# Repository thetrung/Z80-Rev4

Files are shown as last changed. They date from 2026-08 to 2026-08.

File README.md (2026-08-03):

# Z80 Homebrew with PIC18/F4520 
Rev4 of Z80 + PIC18/F4520 setup.

### Note
I have never had a real working Z80 before so this board is designed to test that if I can get one.

### 3D Preview 
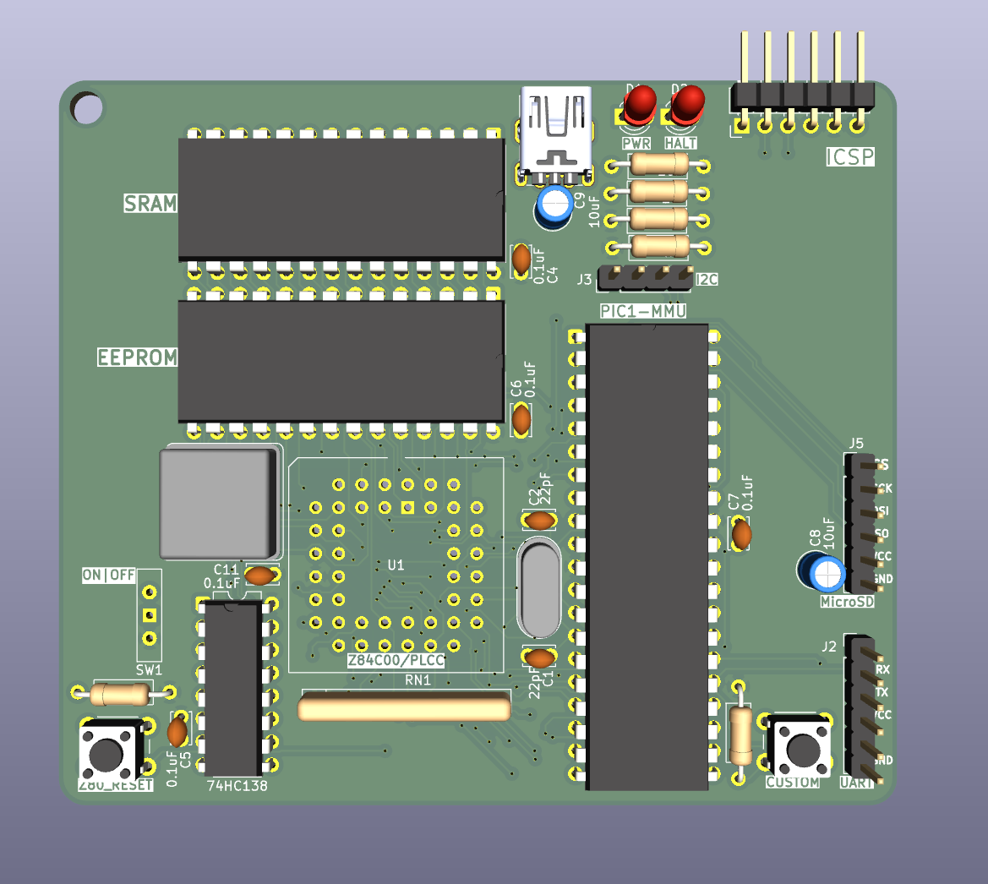
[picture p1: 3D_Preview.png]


### Placement (SilkScreen)
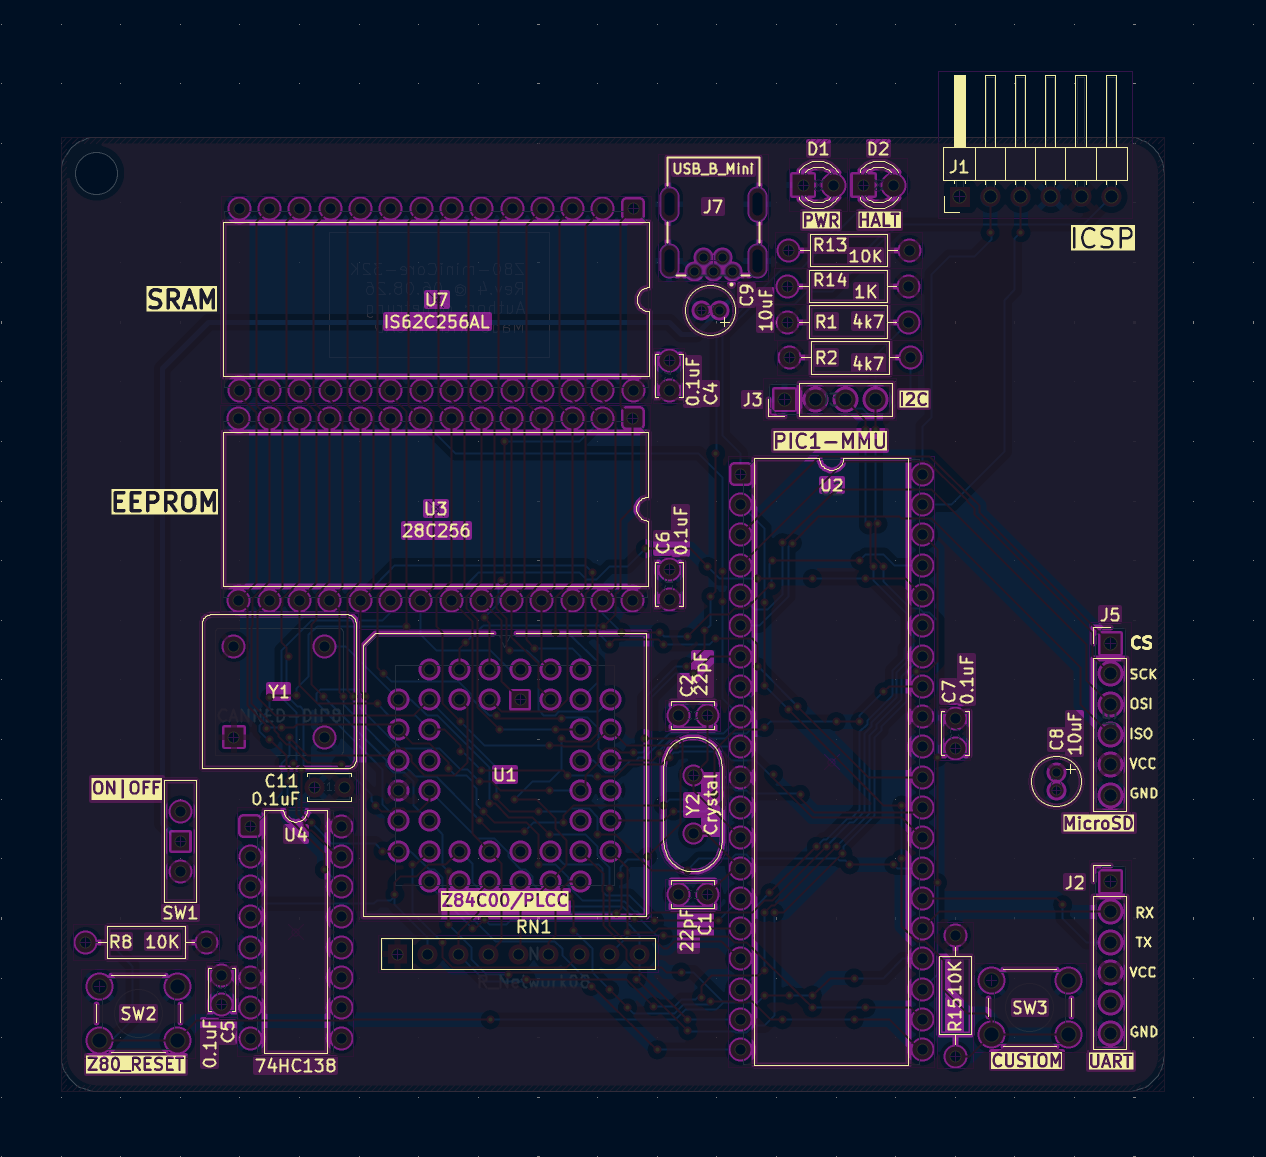
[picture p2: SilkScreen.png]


### Schematic 
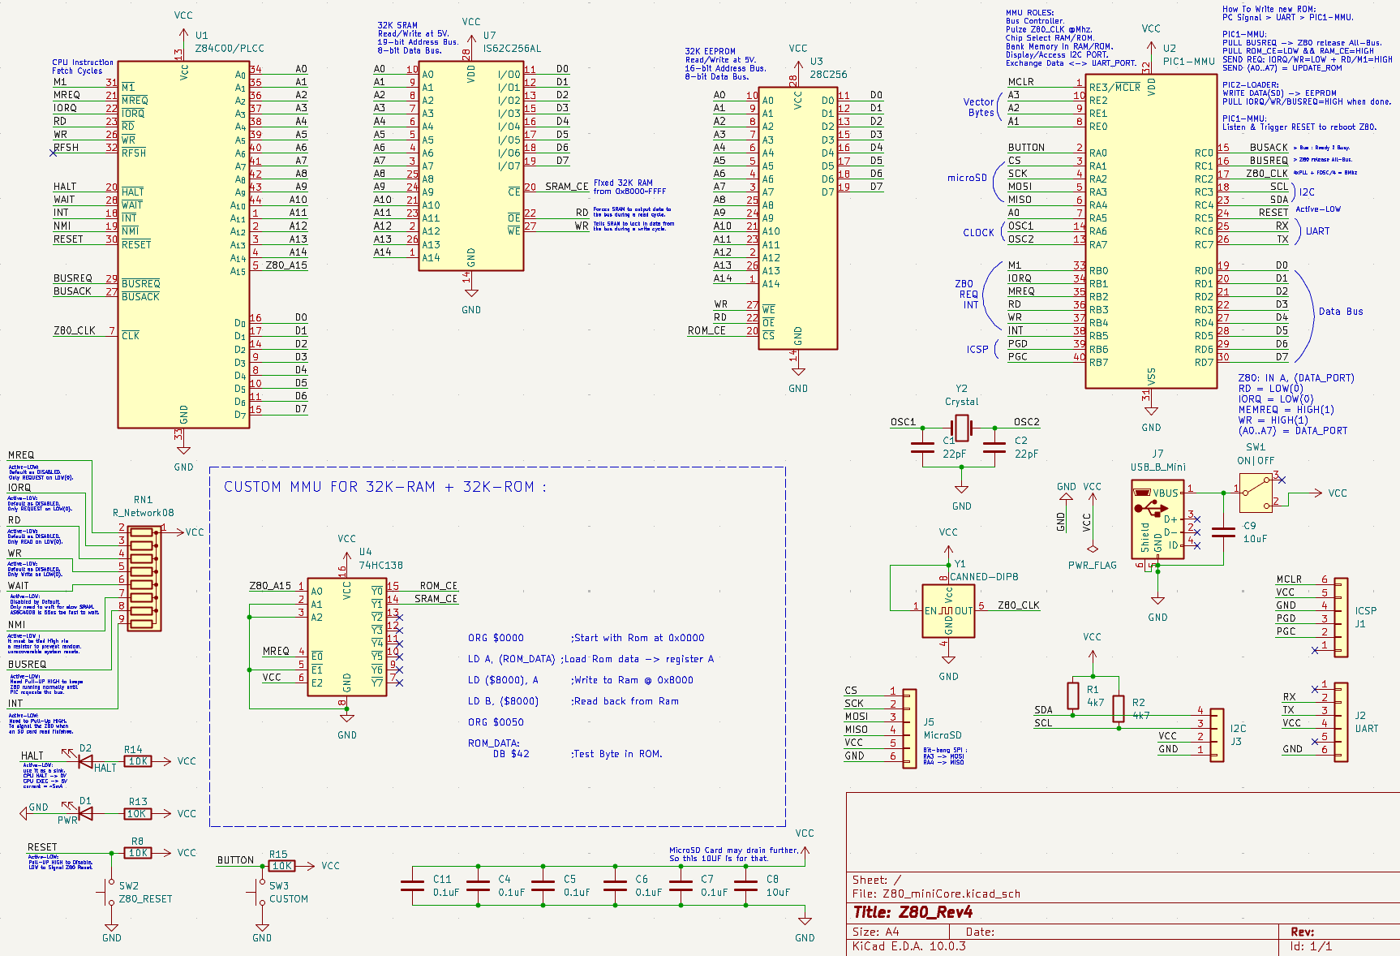
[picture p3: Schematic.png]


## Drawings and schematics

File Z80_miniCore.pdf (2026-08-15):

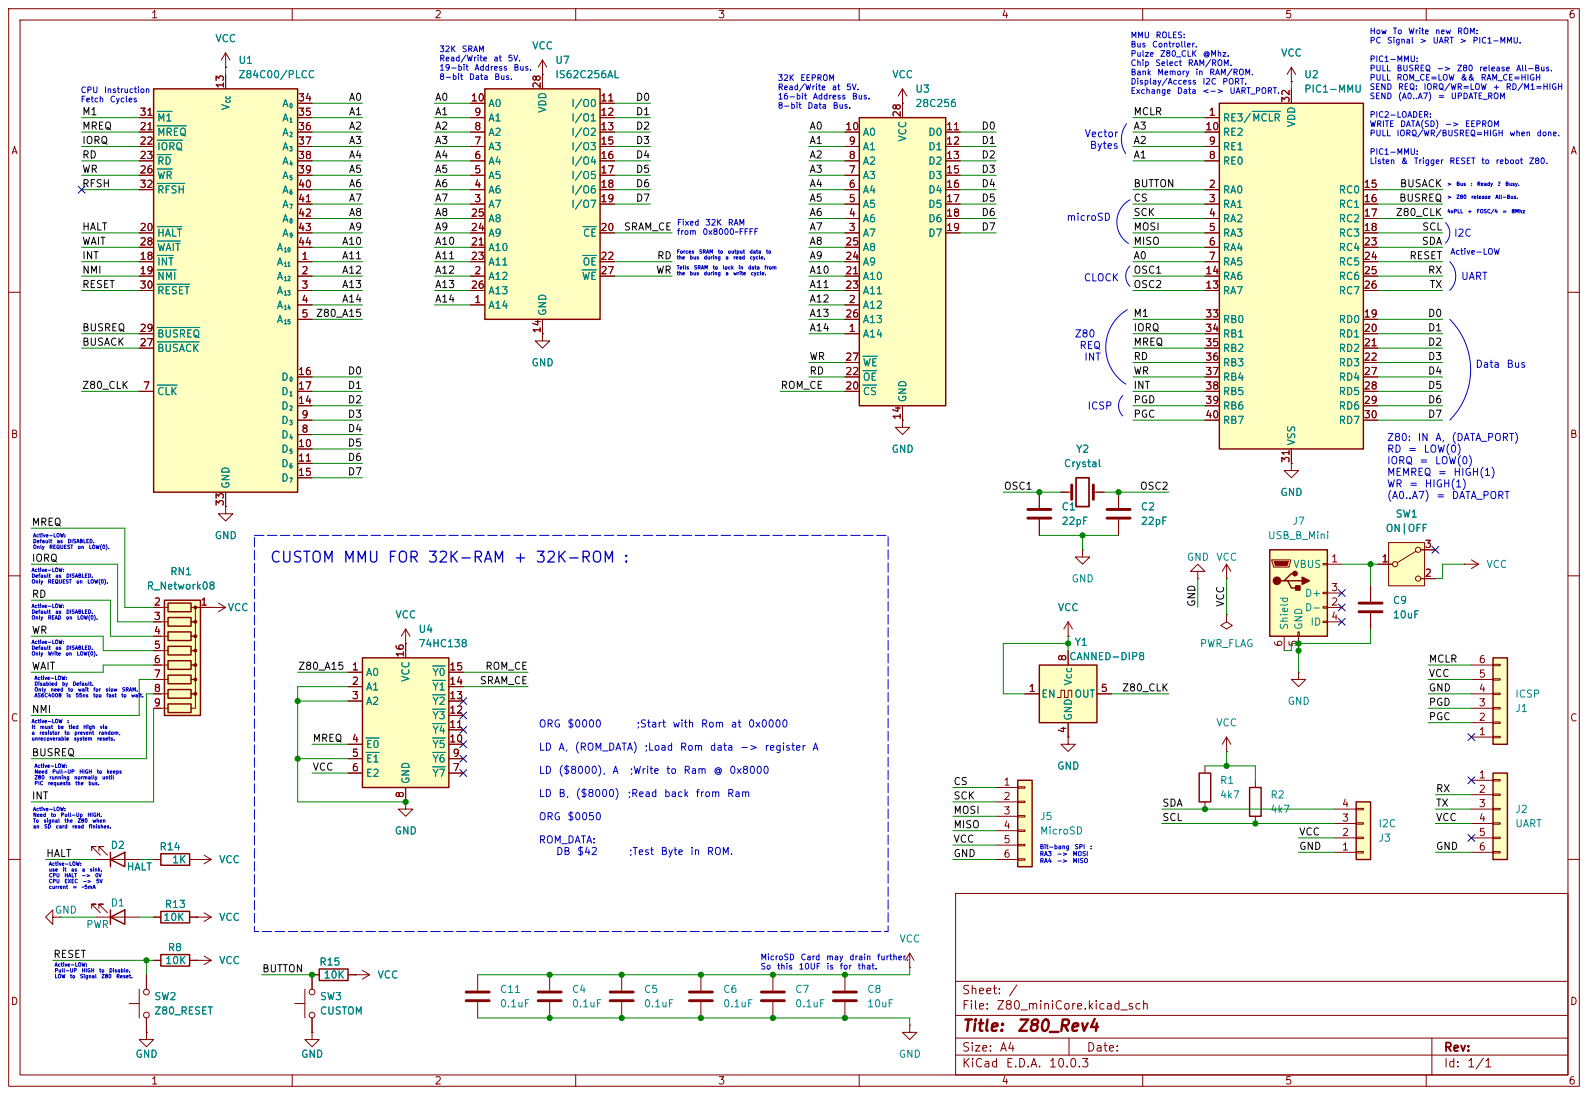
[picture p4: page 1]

VCC U1
INT 18 NMI 19 HALT 20 MREQ 21

MMU ROLES: Bus Controller. Pulze Z80_CLK @Mhz. Chip Select RAM/ROM. Bank Memory in RAM/ROM. Display/Access I2C PORT. Exchange Data <-> UART_PORT.

> Bus : Ready ? Busy. How To Write new ROM: PC Signal > UART > PIC1-MMU. PIC1-MMU: PULL BUSREQ -> Z80 release All-Bus. PULL ROM_CE=LOW && RAM_CE=HIGH
VCC U3

Z84C00/PLCC

32K EEPROM Read/Write at 5V. 16-bit Address Bus. 8-bit Data Bus.

SEND REQ: IORQ/WR=LOW + RD/M1=HIGH
SEND (A0..A7) = UPDATE_ROM

PIC2-LOADER: WRITE DATA(SD) -> EEPROM

PULL IORQ/WR/BUSREQ=HIGH when done. PIC1-MMU: Listen & Trigger RESET to reboot Z80. > Z80 release All-Bus.

Forces SRAM to output data to

Tells SRAM to lock in data from

IORQ = MEMREQ = HIGH(1) WR = HIGH(1)
10uF SW1 ON|OFF 1

(A0..A7) = DATA_PORT MicroSD Card may drain further, So this 10UF is for that.

Active-LOW: Default as DISABLED. Only Write on LOW(0). Active-LOW: Default as DISABLED. Only READ on LOW(0).

Active-LOW :
It must be tied High via a resistor to prevent random, unrecoverable system resets.

LD A, (ROM_DATA) ;Load Rom data -> register A

Active-LOW: Need Pull-UP HIGH to keeps Z80 running normally until PIC requests the bus.

LD ($8000), A ;Write to Ram @ 0x8000

Bit-bang SPI : RA3 -> MOSI RA4 -> MISO

Active-LOW: use it as a sink. CPU HALT -> 0V CPU EXEC -> 5V

Active-LOW: Pull-UP HIGH to Disable. LOW to Signal Z80 Reset.

Size: A4 | Rev:
KiCad E.D.A. 10.0.3 | Id: 1/1

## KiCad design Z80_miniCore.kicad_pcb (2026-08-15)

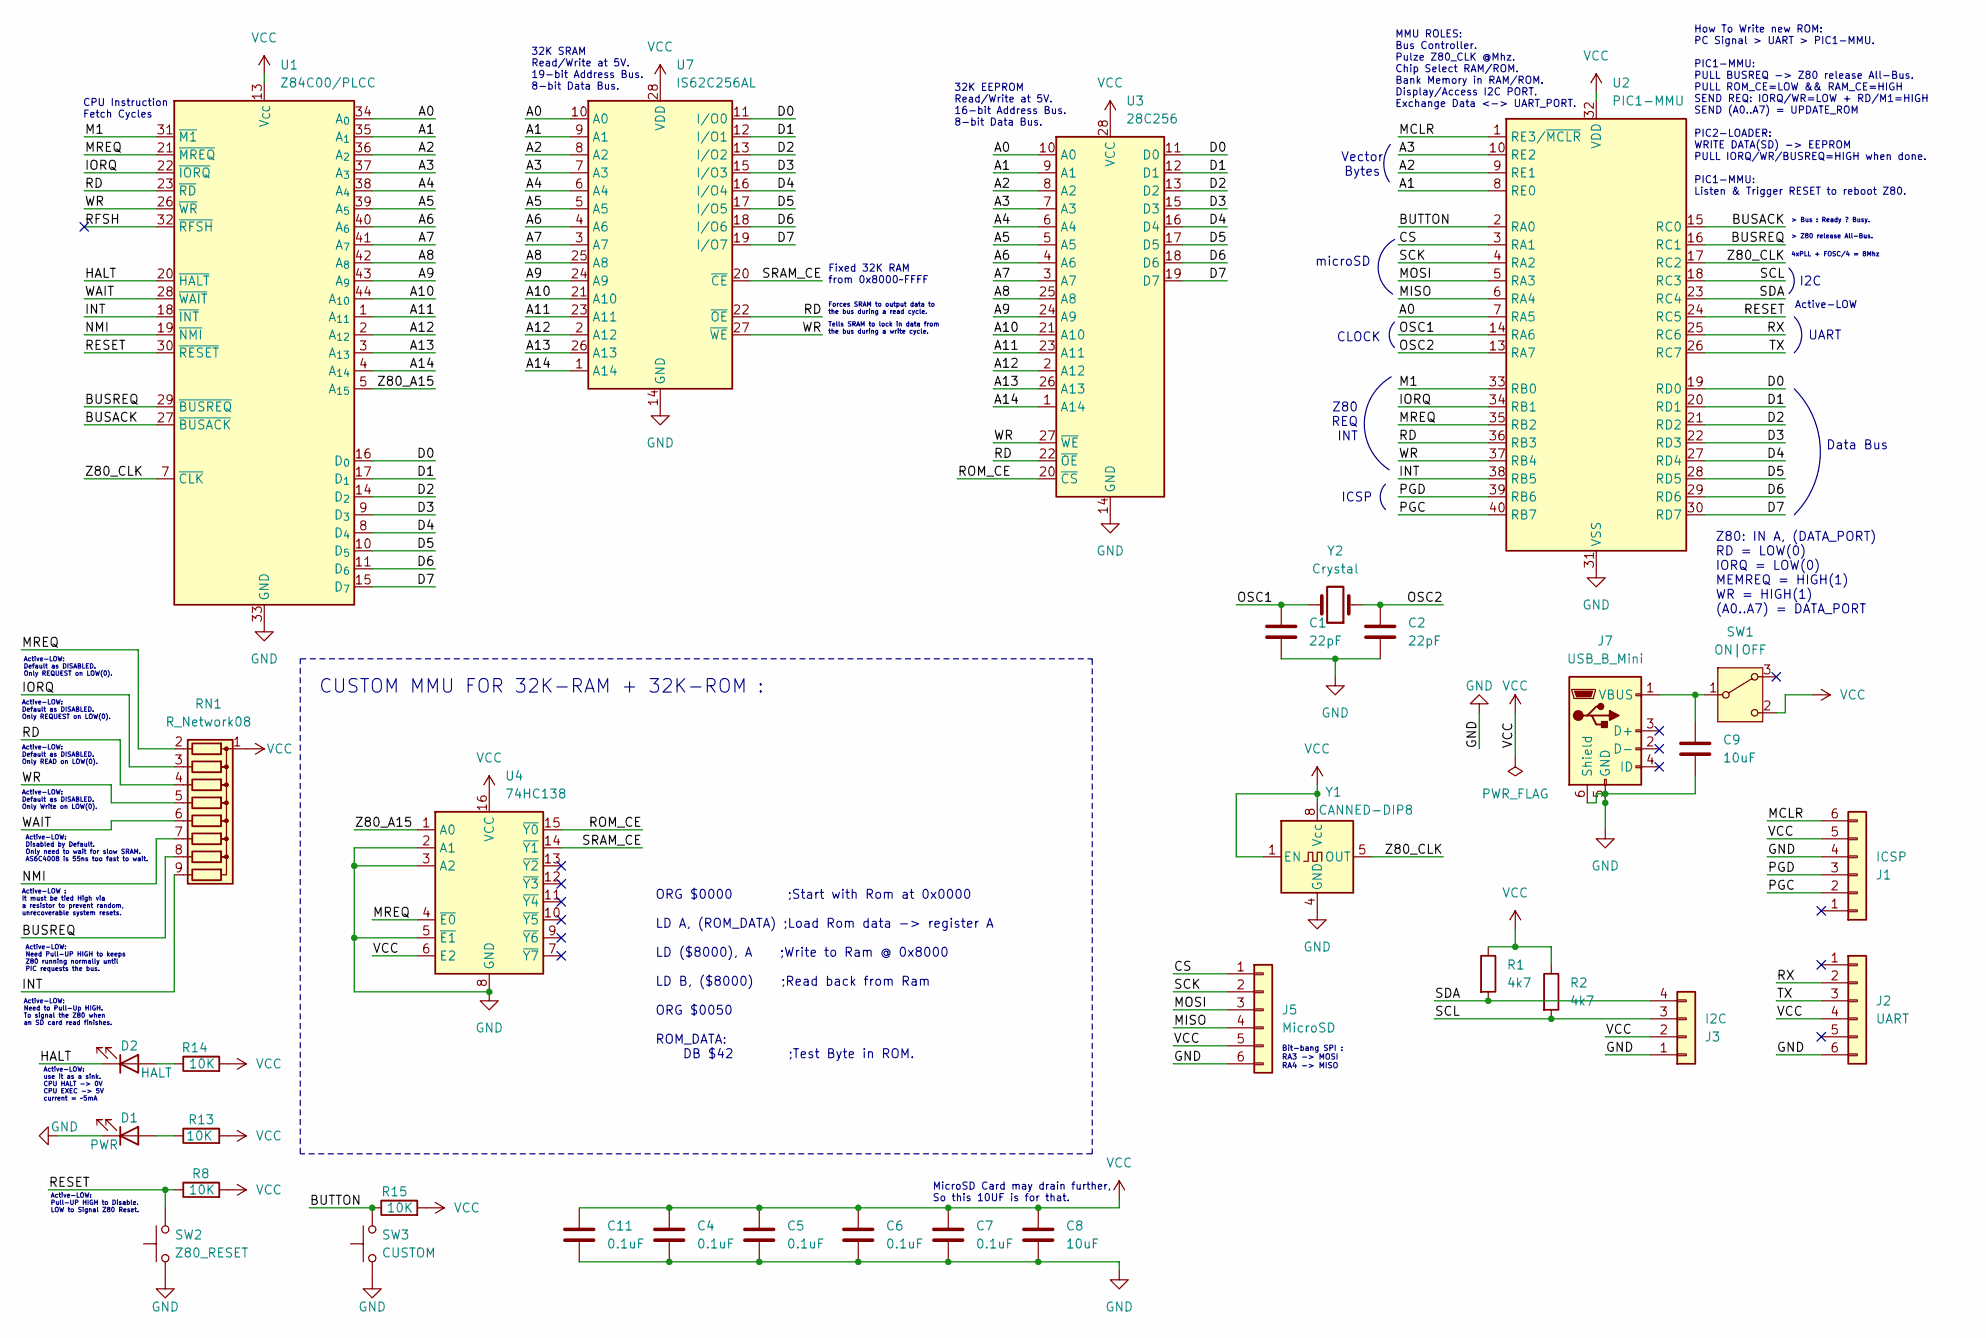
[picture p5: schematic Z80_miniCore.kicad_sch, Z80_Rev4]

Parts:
C1, C2: 22pF; C_Disc_D3.4mm_W2.1mm_P2.50mm
C4, C5, C6, C7, C11: 0.1uF; C_Disc_D3.4mm_W2.1mm_P2.50mm
C8, C9: 10uF; C_Radial_D4.0mm_H5.0mm_P1.50mm
D1: PWR; LED_D3.0mm
D2: HALT; LED_D3.0mm
J1: ICSP; PinHeader_1x06_P2.54mm_Horizontal
J2: UART; PinHeader_1x06_P2.54mm_Vertical
J3: I2C; PinHeader_1x04_P2.54mm_Vertical
J5: MicroSD; PinHeader_1x06_P2.54mm_Vertical
J7: USB_B_Mini; USB_MINI_B_90_Angled
R1, R2: 4k7; R_Axial_DIN0207_L6.3mm_D2.5mm_P10.16mm_Horizontal
R8, R13, R14, R15: 10K; R_Axial_DIN0207_L6.3mm_D2.5mm_P10.16mm_Horizontal
RN1: R_Network08; R_Array_SIP9
SW1: ON|OFF; SW_Slide-03_Wuerth-WS-SLTV_10x2.5x6.4_P2.54mm
SW2: Z80_RESET; SW_PUSH_6mm
SW3: CUSTOM; SW_PUSH_6mm
U1: Z84C00/PLCC; PLCC-44_THT-Socket
U2: PIC1-MMU; DIP-40_W15.24mm
U3: 28C256; DIP-28_W15.24mm
U4: 74HC138; DIP-16_W7.62mm
U7: IS62C256AL; DIP-28_W15.24mm
Y1: CANNED-DIP8; Oscillator_DIP-8
Y2: Crystal; Crystal_HC49-4H_Vertical

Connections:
/A0: U1.34 (A_{0}), U2.7 (RA5), U3.10 (A0), U7.10 (A0)
/A1: U1.35 (A_{1}), U2.8 (RE0), U3.9 (A1), U7.9 (A1)
/A2: U1.36 (A_{2}), U2.9 (RE1), U3.8 (A2), U7.8 (A2)
/A3: U1.37 (A_{3}), U2.10 (RE2), U3.7 (A3), U7.7 (A3)
/A4: U1.38 (A_{4}), U3.6 (A4), U7.6 (A4)
/A5: U1.39 (A_{5}), U3.5 (A5), U7.5 (A5)
/A6: U1.40 (A_{6}), U3.4 (A6), U7.4 (A6)
/A7: U1.41 (A_{7}), U3.3 (A7), U7.3 (A7)
/A8: U1.42 (A_{8}), U3.25 (A8), U7.25 (A8)
/A9: U1.43 (A_{9}), U3.24 (A9), U7.24 (A9)
/A10: U1.44 (A_{10}), U3.21 (A10), U7.21 (A10)
/A11: U1.1 (A_{11}), U3.23 (A11), U7.23 (A11)
/A12: U1.2 (A_{12}), U3.2 (A12), U7.2 (A12)
/A13: U1.3 (A_{13}), U3.26 (A13), U7.26 (A13)
/A14: U1.4 (A_{14}), U3.1 (A14), U7.1 (A14)
/BUSACK: U1.27 (~BUSACK), U2.15 (RC0)
/BUSREQ: RN1.8 (R7), U1.29 (~BUSREQ), U2.16 (RC1)
/BUTTON: R15.1, SW3.2, U2.2 (RA0)
/CS: J5.1, U2.3 (RA1)
/D0: U1.16 (D_{0}), U2.19 (RD0), U3.11 (D0), U7.11 (I/O0)
/D1: U1.17 (D_{1}), U2.20 (RD1), U3.12 (D1), U7.12 (I/O1)
/D2: U1.14 (D_{2}), U2.21 (RD2), U3.13 (D2), U7.13 (I/O2)
/D3: U1.9 (D_{3}), U2.22 (RD3), U3.15 (D3), U7.15 (I/O3)
/D4: U1.8 (D_{4}), U2.27 (RD4), U3.16 (D4), U7.16 (I/O4)
/D5: U1.10 (D_{5}), U2.28 (RD5), U3.17 (D5), U7.17 (I/O5)
/D6: U1.11 (D_{6}), U2.29 (RD6), U3.18 (D6), U7.18 (I/O6)
/D7: U1.15 (D_{7}), U2.30 (RD7), U3.19 (D7), U7.19 (I/O7)
/HALT: D2.1 (K), U1.20 (~HALT)
/INT: RN1.9 (R8), U1.18 (~INT), U2.38 (RB5)
/IORQ: RN1.3 (R2), U1.22 (~IORQ), U2.34 (RB1)
/M1: U1.31 (~M1), U2.33 (RB0)
/MCLR: J1.6, U2.1 (RE3/~MCLR)
/MISO: J5.4, U2.6 (RA4)
/MOSI: J5.3, U2.5 (RA3)
/MREQ: RN1.2 (R1), U1.21 (~MREQ), U2.35 (RB2), U4.4 (~E0)
/NMI: RN1.7 (R6), U1.19 (~NMI)
/OSC1: C1.1, U2.14 (RA6), Y2.2
/OSC2: C2.1, U2.13 (RA7), Y2.1
/PGC: J1.2, U2.40 (RB7)
/PGD: J1.3, U2.39 (RB6)
/RD: RN1.4 (R3), U1.23 (~RD), U2.36 (RB3), U3.22 (~OE), U7.22 (~OE)
/RESET: R8.1, SW2.2, U1.30 (~RESET), U2.24 (RC5)
/RFSH: U1.32 (~RFSH)
/ROM_CE: U3.20 (~CS), U4.15 (~Y0)
/RX: J2.2, U2.25 (RC6)
/SCK: J5.2, U2.4 (RA2)
/SCL: J3.3, R2.2, U2.18 (RC3)
/SDA: J3.4, R1.2, U2.23 (RC4)
/SRAM_CE: U4.14 (~Y1), U7.20 (~CE)
/TX: J2.3, U2.26 (RC7)
/WAIT: RN1.6 (R5), U1.28 (~WAIT)
/WR: RN1.5 (R4), U1.26 (~WR), U2.37 (RB4), U3.27 (~WE), U7.27 (~WE)
/Z80_A15: U1.5 (A_{15}), U4.1 (A0)
/Z80_CLK: U1.7 (~CLK), U2.17 (RC2), Y1.5 (OUT)
GND: C1.2, C2.2, C4.1, C5.1, C6.1, C7.1, C8.1, C9.1, C11.1, D1.1 (K), J1.4, J2.6, J3.1, J5.6, J7.5 (GND), J7.6 (Shield), SW2.1, SW3.1, U1.33 (GND), U2.12 (VSS), U2.31 (VSS), U3.14 (GND), U4.2 (A1), U4.3 (A2), U4.5 (~E1), U4.8 (GND), U7.14 (GND), Y1.4 (GND)
unnamed: D1.2 (A), R13.1
unnamed: D2.2 (A), R14.1
unnamed: C9.2, J7.1 (VBUS), SW1.1 (B)
VCC: C4.2, C5.2, C6.2, C7.2, C8.2, C11.2, J1.5, J2.4, J3.2, J5.5, R1.1, R2.1, R8.2, R13.2, R14.2, R15.2, RN1.1 (common), SW1.2 (C), U1.13 (V_{CC}), U2.11 (VDD), U2.32 (VDD), U3.28 (VCC), U4.6 (E2), U4.16 (VCC), U7.28 (VDD), Y1.1 (EN), Y1.8 (Vcc)

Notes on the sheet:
microSD
Active-LOW: Default as DISABLED. Only REQUEST on LOW(0).
Active-LOW: Need to Pull-Up HIGH. To signal the Z80 when an SD card read finishes.
Tells SRAM to lock in data from the bus during a write cycle.
32K SRAM Read/Write at 5V. 19-bit Address Bus. 8-bit Data Bus.
Active-LOW: use it as a sink. CPU HALT -> 0V CPU EXEC -> 5V current = ~5mA
Active-LOW: Default as DISABLED. Only READ on LOW(0).
ICSP
CLOCK
> Bus : Ready ? Busy.
ORG $0000 ;Start with Rom at 0x0000 LD A, (ROM_DATA) ;Load Rom data -> register A LD ($8000), A ;Write to Ram @ 0x8000 LD B, ($8000) ;Read back from Ram ORG $0050 ROM_DATA: DB $42 ;Test Byte in ROM.
Data Bus
Z80 REQ INT
Forces SRAM to output data to the bus during a read cycle.
MMU ROLES: Bus Controller. Pulze Z80_CLK @Mhz. Chip Select RAM/ROM. Bank Memory in RAM/ROM. Display/Access I2C PORT. Exchange Data <-> UART_PORT.
32K EEPROM Read/Write at 5V. 16-bit Address Bus. 8-bit Data Bus.
Active-LOW: Disabled by Default. Only need to wait for slow SRAM. AS6C4008 is 55ns too fast to wait.
Active-LOW: Need Pull-UP HIGH to keeps Z80 running normally until PIC requests the bus.
I2C
MicroSD Card may drain further, So this 10UF is for that.
Active-LOW : It must be tied High via a resistor to prevent random, unrecoverable system resets.
Active-LOW: Pull-UP HIGH to Disable. LOW to Signal Z80 Reset.
4xPLL + FOSC/4 = 8Mhz
Active-LOW: Default as DISABLED. Only Write on LOW(0).
Fixed 32K RAM from 0x8000~FFFF
CUSTOM MMU FOR 32K-RAM + 32K-ROM :
Bit-bang SPI : RA3 -> MOSI RA4 -> MISO
Active-LOW
CPU Instruction Fetch Cycles
How To Write new ROM: PC Signal > UART > PIC1-MMU. PIC1-MMU: PULL BUSREQ -> Z80 release All-Bus. PULL ROM_CE=LOW && RAM_CE=HIGH SEND REQ: IORQ/WR=LOW + RD/M1=HIGH SEND (A0..A7) = UPDATE_ROM PIC2-LOADER: WRITE DATA(SD) -> EEPROM PULL IORQ/WR/BUSREQ=HIGH when done. PIC1-MMU: Listen & Trigger RESET to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
> Z80 release All-Bus.
UART
Z80: IN A, (DATA_PORT) RD = LOW(0) IORQ = LOW(0) MEMREQ = HIGH(1) WR = HIGH(1) (A0..A7) = DATA_PORT
Vector Bytes

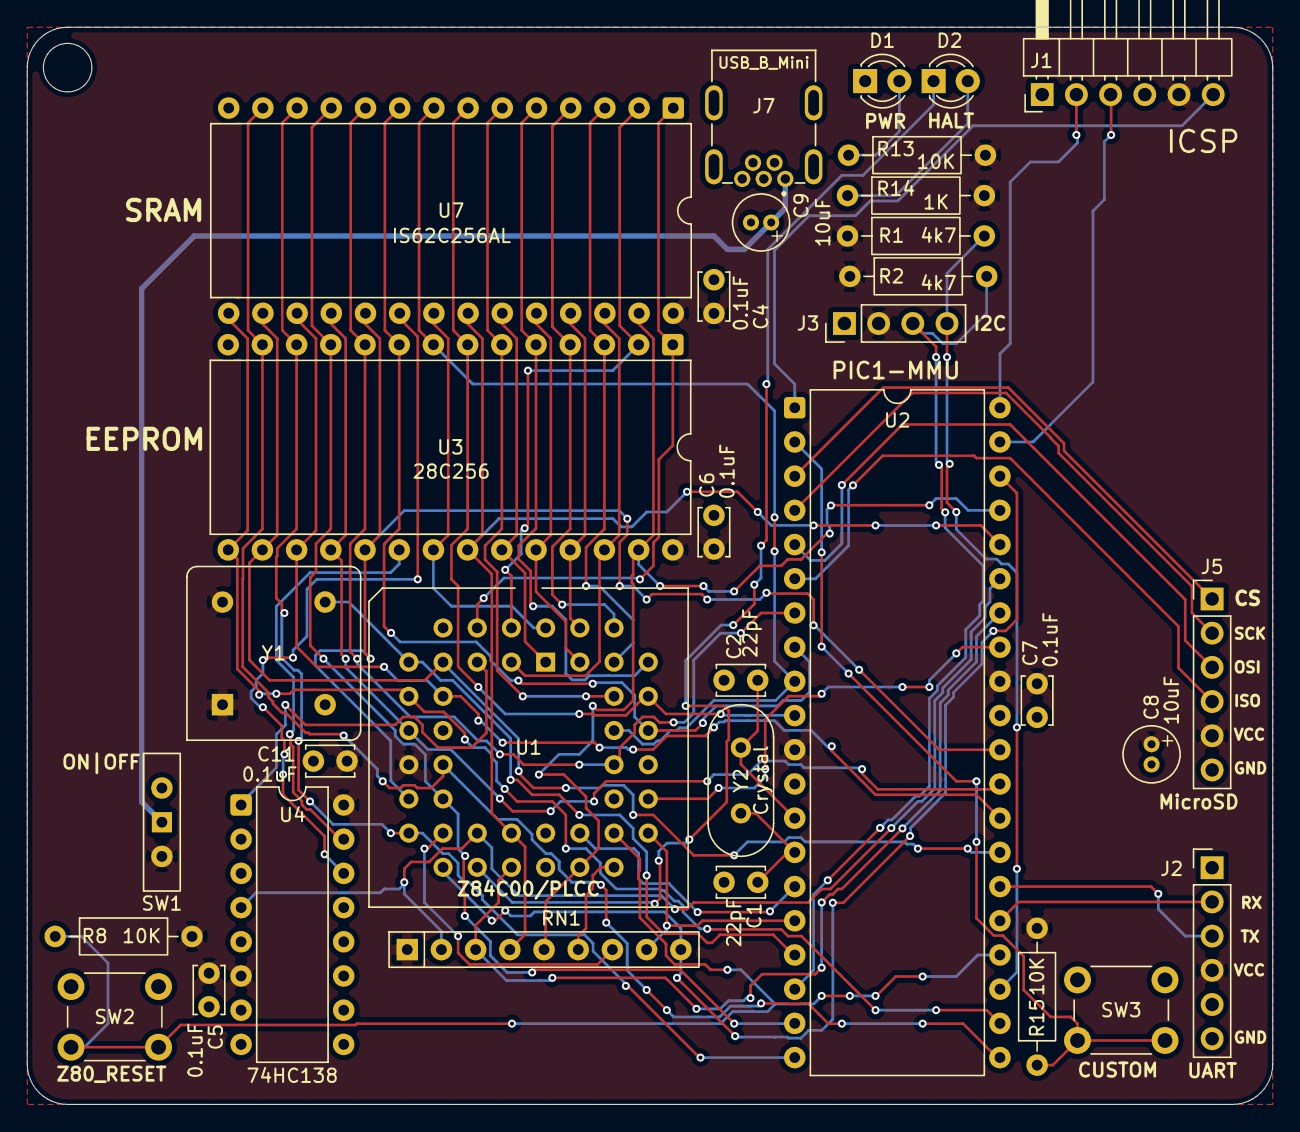
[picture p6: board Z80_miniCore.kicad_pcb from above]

Board: 2 copper layers, 92.5 x 80.0 mm, 33 parts (0 on the bottom side), 58 nets.

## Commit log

2026-08-03 Rev.4 of Z80+PIC Design.
    [Z80_miniCore.kicad_pcb, Z80_miniCore.kicad_sch]
2026-08-03 add footprints for 595 + SST39SF
    [Z80_miniCore.kicad_sch]
2026-08-03 Remove Daisy Chain.
    [Z80_miniCore.kicad_pcb, Z80_miniCore.kicad_sch]
2026-08-04 Add PIC2 as LOADER.
    [Z80_miniCore.kicad_sch]
2026-08-04 change ROM/footprint -> PLCC32
    [Z80_miniCore.kicad_pcb, Z80_miniCore.kicad_sch]
2026-08-04 Add MMU for ROM:Fixed 16K + Swappable 16K + RAM:32K setup.
    [Z80_miniCore.kicad_sch]
2026-08-04 fix branch link for Schematic.
2026-08-05 Replace ROM + MMU/74HC138.
    [Z80_miniCore.kicad_pcb, Z80_miniCore.kicad_sch]
2026-08-05 Add Holes > PCB.
    [Z80_miniCore.kicad_pcb]
2026-08-05 finish routing.
    [Z80_miniCore.kicad_pcb, Z80_miniCore.kicad_sch]
2026-08-05 Generate FAB
    [Z80_miniCore.kicad_pcb]
2026-08-15 Replace 8x10K_R w/ 1xRN8. Refine footprints.
    [Z80_miniCore.kicad_pcb, Z80_miniCore.kicad_sch]
2026-08-19 Refine schematic: convert all R-10K-> RN8 & fix ICSP.
    [Z80_miniCore.kicad_sch]
